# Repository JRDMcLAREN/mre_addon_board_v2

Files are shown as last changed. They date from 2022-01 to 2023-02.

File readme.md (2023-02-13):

# mre_addon_board_v2

Addon board for microrusEFI ECU.
Wideband controller wiring is based on https://github.com/mck1117/wideband, official rusEFI wideband controller.
This is a version using STM32F072C8Tx or STM32F072CBTx MCU in LQFP48 package.
(STM32F042C6T6 is not recommended for future release)

This addon board has build-in rusEFI wideband controller, microSD card slot and K-Thermocouple controller.
It can be used on all MREs with appropriate connector headers.

Wideband controller requires:
* CAN bus connectivity 
* additional power supply from 12V_MREL pin for sensor heater.
(not required for "my" MRE versions - R0.5.5rc, R0.6.1rc)

~~LSU 4.9 sensor wires are connected via MOLEX MicroFit 3x2 connector 43045-0601 or 43045-0612
K-Thermocouple wires are connected via MOLEX MicroFit 2x1 connector 43045-0202 or 43045-0212~~

Latest version use 2x4 pin connector MOLEX 43045-0800 or 43045-0812 (6pins for LSU and 2pins for K-Thermocouple).

Two analog outputs for external gauages are in progress.

SPI ChipSelect CS# pins:
PA15 - for EGT chip
PB9 - for microSD card

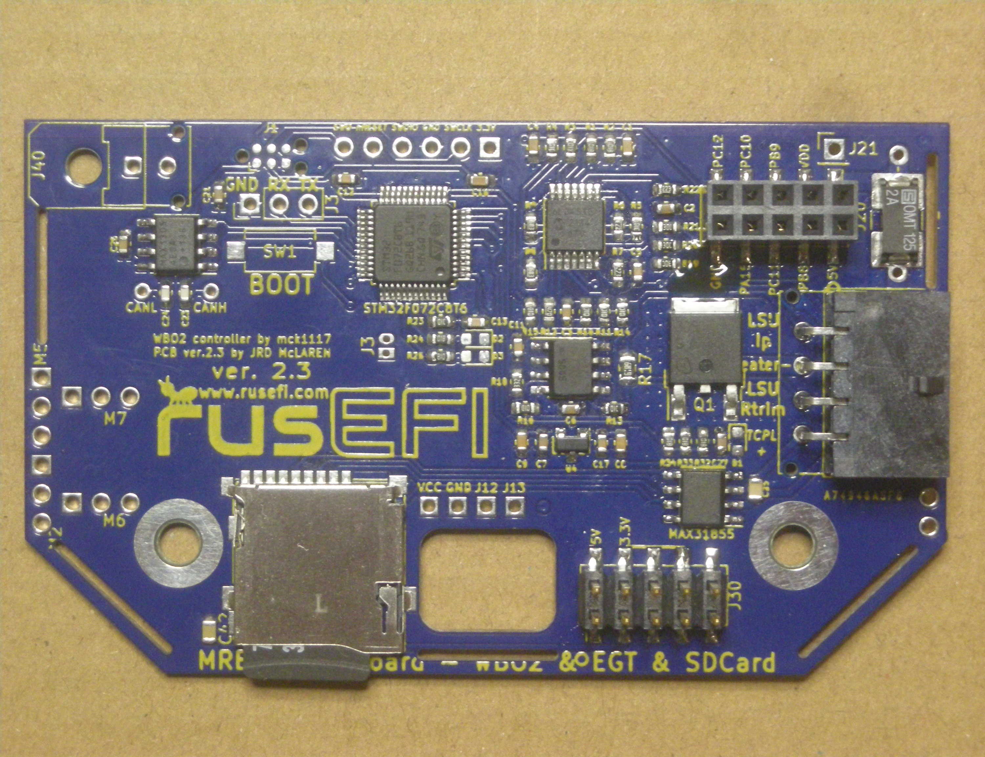
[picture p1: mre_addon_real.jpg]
mre_addon_board_v2


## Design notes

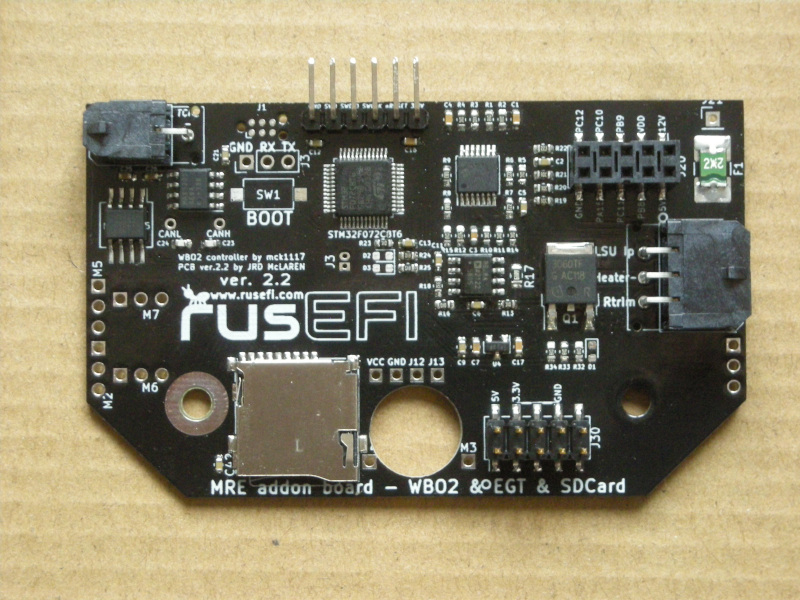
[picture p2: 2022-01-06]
mre_addon_real_v22.jpg

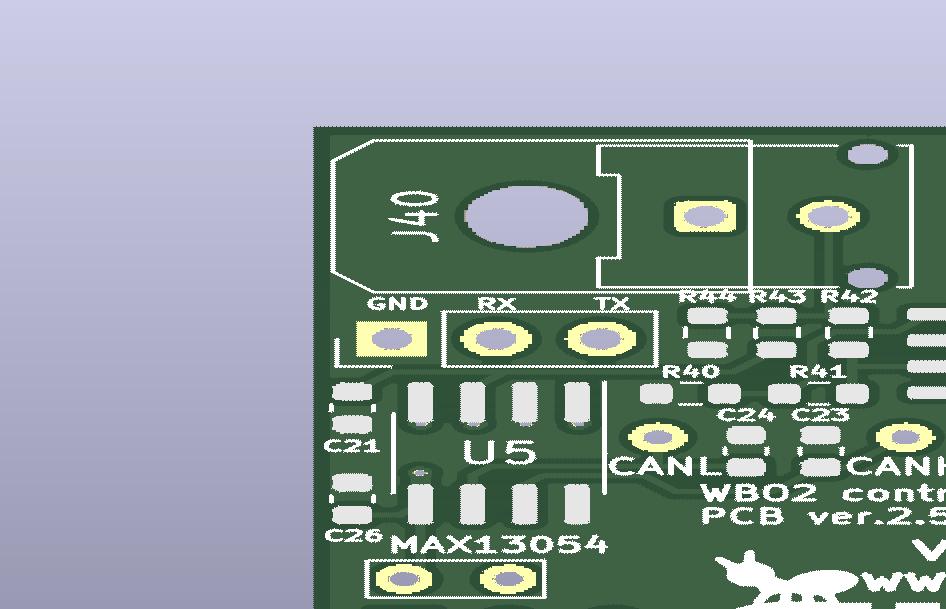
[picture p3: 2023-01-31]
mre_addon_v2.jpg

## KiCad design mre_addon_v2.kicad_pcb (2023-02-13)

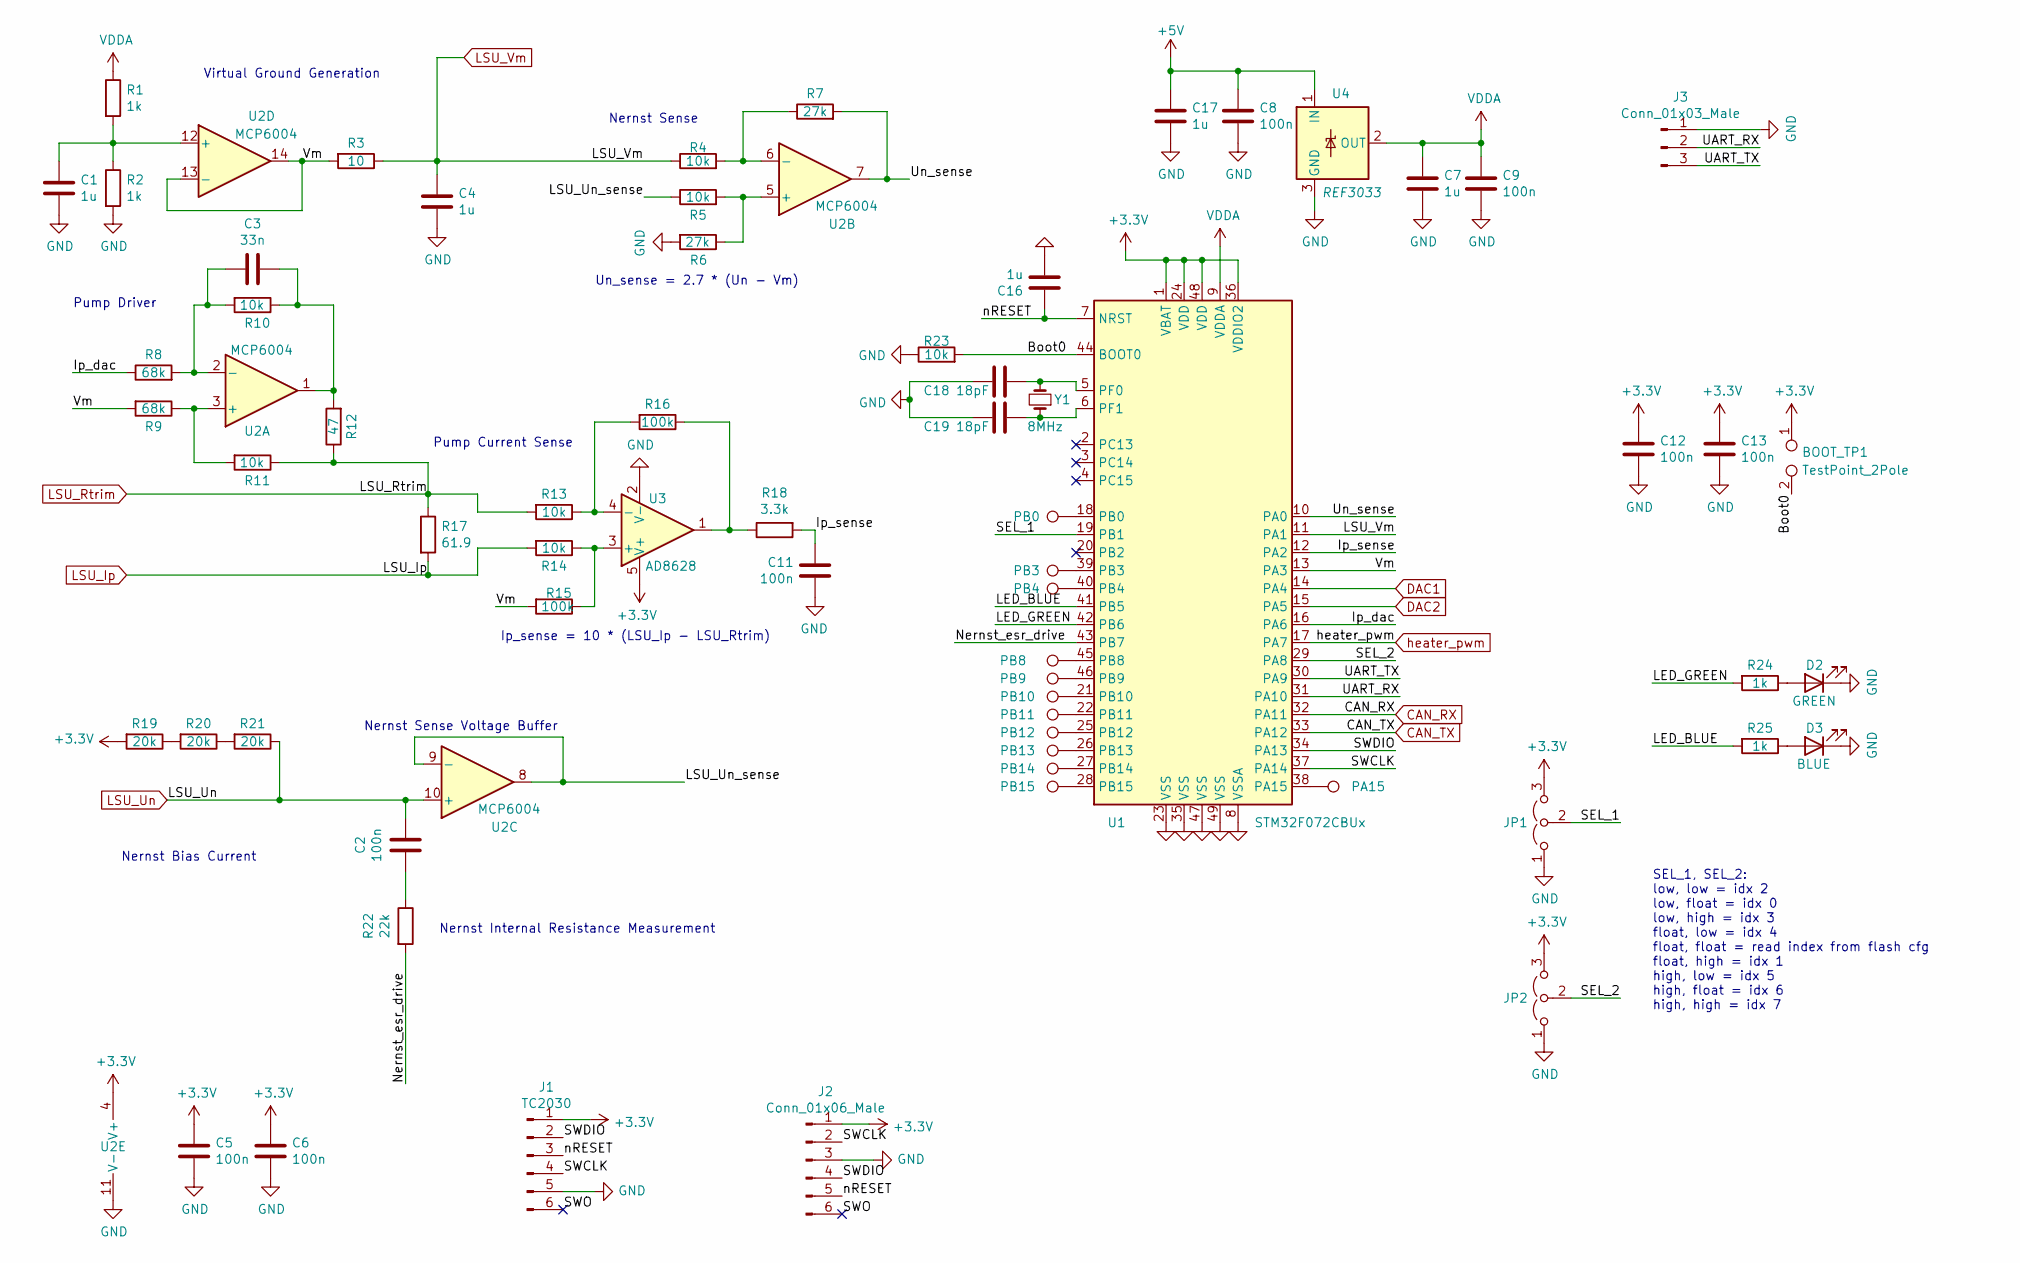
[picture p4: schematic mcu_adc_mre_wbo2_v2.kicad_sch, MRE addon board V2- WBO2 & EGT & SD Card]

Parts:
BOOT_TP1: TestPoint_2Pole; TestPoint_Bridge_Pitch2.54mm_Drill0.7mm
C1, C4, C7, C16, C17: 1u; C_0603_1608Metric; LCSC C52923
C2, C5, C6, C9, C11, C12, C13: 100n; C_0603_1608Metric; LCSC C1525
C3: 33n; C_0603_1608Metric; LCSC C1585
C8: 100n; C_0603_1608Metric
C18, C19: 18pF; C_0603_1608Metric
D2: GREEN; LED_0603_1608Metric; LCSC C72043
D3: BLUE; LED_0603_1608Metric; LCSC C72041
J1: TC2030; Tag-Connect_TC2030-IDC-NL_2x03_P1.27mm_Vertical
J2: Conn_01x06_Male; PinHeader_1x06_P2.54mm_Vertical
J3: Conn_01x03_Male; PinHeader_1x03_P2.54mm_Vertical
JP1, JP2: Jumper_3_Open; SolderJumper-3_P1.3mm_Open_Pad1.0x1.5mm
PA15: TestPoint; TestPoint_Pad_D1.0mm
PB0, PB3, PB4, PB8, PB9, PB10, PB11, PB12, PB13, PB14, PB15: TestPoint; TestPoint_Pad_D1.0mm
R1, R2, R24, R25: 1k; R_0603_1608Metric; LCSC C11702
R3: 10; R_0603_1608Metric; LCSC C25077
R4, R5, R10, R11, R13, R14, R23: 10k; R_0603_1608Metric; LCSC C25744
R6, R7: 27k; R_0603_1608Metric; LCSC C25771
R8, R9: 68k; R_0603_1608Metric; LCSC C36871
R12: 47; R_0603_1608Metric; LCSC C25118
R15, R16: 100k; R_0603_1608Metric; LCSC C25741
R17: 61.9; R_0603_1608Metric; LCSC C23092
R18: 3.3k; R_0603_1608Metric; LCSC C25890
R19, R20, R21: 20k; R_0603_1608Metric; LCSC C25765
R22: 22k; R_0603_1608Metric; LCSC C25768
U1: STM32F072CBUx; LQFP-48_7x7mm_P0.5mm
U2: MCP6004; TSSOP-14_4.4x5mm_P0.65mm; LCSC C50282
U3: AD8628; TSOT-23-5; LCSC C29309
U4: REF3033; SOT-23; LCSC C36658
Y1: 8MHz; Crystal_SMD_5032-2Pin_5.0x3.2mm

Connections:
+3.3V: BOOT_TP1.1, C5.1, C6.1, C12.1, C13.1, J1.1, J2.1, JP1.3 (B), JP2.3 (B), R19.2, U1.1 (VBAT), U1.24 (VDD), U1.36 (VDDIO2), U1.48 (VDD), U2.4 (V+), U3.5 (V+); also elsewhere on the board
+5V: C8.1, C17.1, U4.1 (IN); also elsewhere on the board
/mcu_adc_mre_wbo2_v2/Boot0: BOOT_TP1.2, R23.2, U1.44 (BOOT0)
/mcu_adc_mre_wbo2_v2/Ip_dac: R8.1, U1.16 (PA6)
/mcu_adc_mre_wbo2_v2/Ip_sense: C11.1, R18.2, U1.12 (PA2)
/mcu_adc_mre_wbo2_v2/LED_BLUE: R25.2, U1.41 (PB5)
/mcu_adc_mre_wbo2_v2/LED_GREEN: R24.2, U1.42 (PB6)
/mcu_adc_mre_wbo2_v2/LSU_Un_sense: R5.1, U2.8, U2.9 (-)
/mcu_adc_mre_wbo2_v2/Nernst_esr_drive: R22.2, U1.43 (PB7)
/mcu_adc_mre_wbo2_v2/SEL_1: JP1.2 (C), U1.19 (PB1)
/mcu_adc_mre_wbo2_v2/SEL_2: JP2.2 (C), U1.29 (PA8)
/mcu_adc_mre_wbo2_v2/SWCLK: J1.4, J2.2, U1.37 (PA14); also elsewhere on the board
/mcu_adc_mre_wbo2_v2/SWDIO: J1.2, J2.4, U1.34 (PA13); also elsewhere on the board
/mcu_adc_mre_wbo2_v2/SWO: J1.6, J2.6; also elsewhere on the board
/mcu_adc_mre_wbo2_v2/UART_RX: J3.2, U1.31 (PA10)
/mcu_adc_mre_wbo2_v2/UART_TX: J3.3, U1.30 (PA9)
/mcu_adc_mre_wbo2_v2/Un_sense: R7.2, U1.10 (PA0), U2.7
/mcu_adc_mre_wbo2_v2/Vm: R3.2, R9.2, R15.2, U1.13 (PA3), U2.13 (-), U2.14
/mcu_adc_mre_wbo2_v2/nRESET: C16.1, J1.3, J2.5, U1.7 (NRST); also elsewhere on the board
CAN_RX: U1.32 (PA11); also elsewhere on the board
CAN_TX: U1.33 (PA12); also elsewhere on the board
DAC1: U1.14 (PA4); also elsewhere on the board
DAC2: U1.15 (PA5); also elsewhere on the board
GND: C1.2, C4.2, C5.2, C6.2, C7.2, C8.2, C9.2, C11.2, C12.2, C13.2, C16.2, C17.2, C18.1, C19.1, D2.1 (K), D3.1 (K), J1.5, J2.3, J3.1, JP1.1 (A), JP2.1 (A), R2.2, R6.2, R23.1, U1.8 (VSSA), U1.23 (VSS), U1.35 (VSS), U1.47 (VSS), U1.49 (VSS), U2.11 (V-), U3.2 (V-), U4.3 (GND); also elsewhere on the board
LSU_Ip: R14.2, R17.2; also elsewhere on the board
LSU_Rtrim: R11.1, R12.1, R13.2, R17.1; also elsewhere on the board
LSU_Un: C2.1, R21.1, U2.10 (+); also elsewhere on the board
LSU_Vm: C4.1, R3.1, R4.1, U1.11 (PA1); also elsewhere on the board
unnamed: C1.1, R1.2, R2.1, U2.12 (+)
unnamed: C2.2, R22.1
unnamed: C3.1, R10.1, R12.2, U2.1
unnamed: C3.2, R8.2, R10.2, U2.2 (-)
unnamed: C18.2, U1.5 (PF0), Y1.2
unnamed: C19.2, U1.6 (PF1), Y1.1
unnamed 54: D2.2 (A), R24.1; also elsewhere on the board
unnamed 55: D3.2 (A), R25.1; also elsewhere on the board
unnamed: PA15.1, U1.38 (PA15)
unnamed: PB0.1, U1.18 (PB0)
unnamed: PB3.1, U1.39 (PB3)
unnamed: PB4.1, U1.40 (PB4)
unnamed: PB8.1, U1.45 (PB8)
unnamed: PB9.1, U1.46 (PB9)
unnamed: PB10.1, U1.21 (PB10)
unnamed: PB11.1, U1.22 (PB11)
unnamed: PB12.1, U1.25 (PB12)
unnamed: PB13.1, U1.26 (PB13)
unnamed: PB14.1, U1.27 (PB14)
unnamed: PB15.1, U1.28 (PB15)
unnamed: R4.2, R7.1, U2.6 (-)
unnamed: R5.2, R6.1, U2.5 (+)
unnamed: R9.1, R11.2, U2.3 (+)
unnamed 72: R13.1, R16.2, U3.4 (-); also elsewhere on the board
unnamed 73: R14.1, R15.1, U3.3 (+); also elsewhere on the board
unnamed 74: R16.1, R18.1, U3.1; also elsewhere on the board
unnamed: R19.1, R20.2
unnamed: R20.1, R21.2
VDDA: C7.1, C9.1, R1.1, U1.9 (VDDA), U4.2 (OUT)
heater_pwm: U1.17 (PA7); also elsewhere on the board

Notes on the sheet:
Un_sense = 2.7 * (Un - Vm)
Virtual Ground Generation
Pump Current Sense
Pump Driver
Ip_sense = 10 * (LSU_Ip - LSU_Rtrim)
Nernst Sense
Nernst Internal Resistance Measurement
Nernst Sense Voltage Buffer
SEL_1, SEL_2: low, low = idx 2 low, float = idx 0 low, high = idx 3 float, low = idx 4 float, float = read index from flash cfg float, high = idx 1 high, low = idx 5 high, float = idx 6 high, high = idx 7
Nernst Bias Current

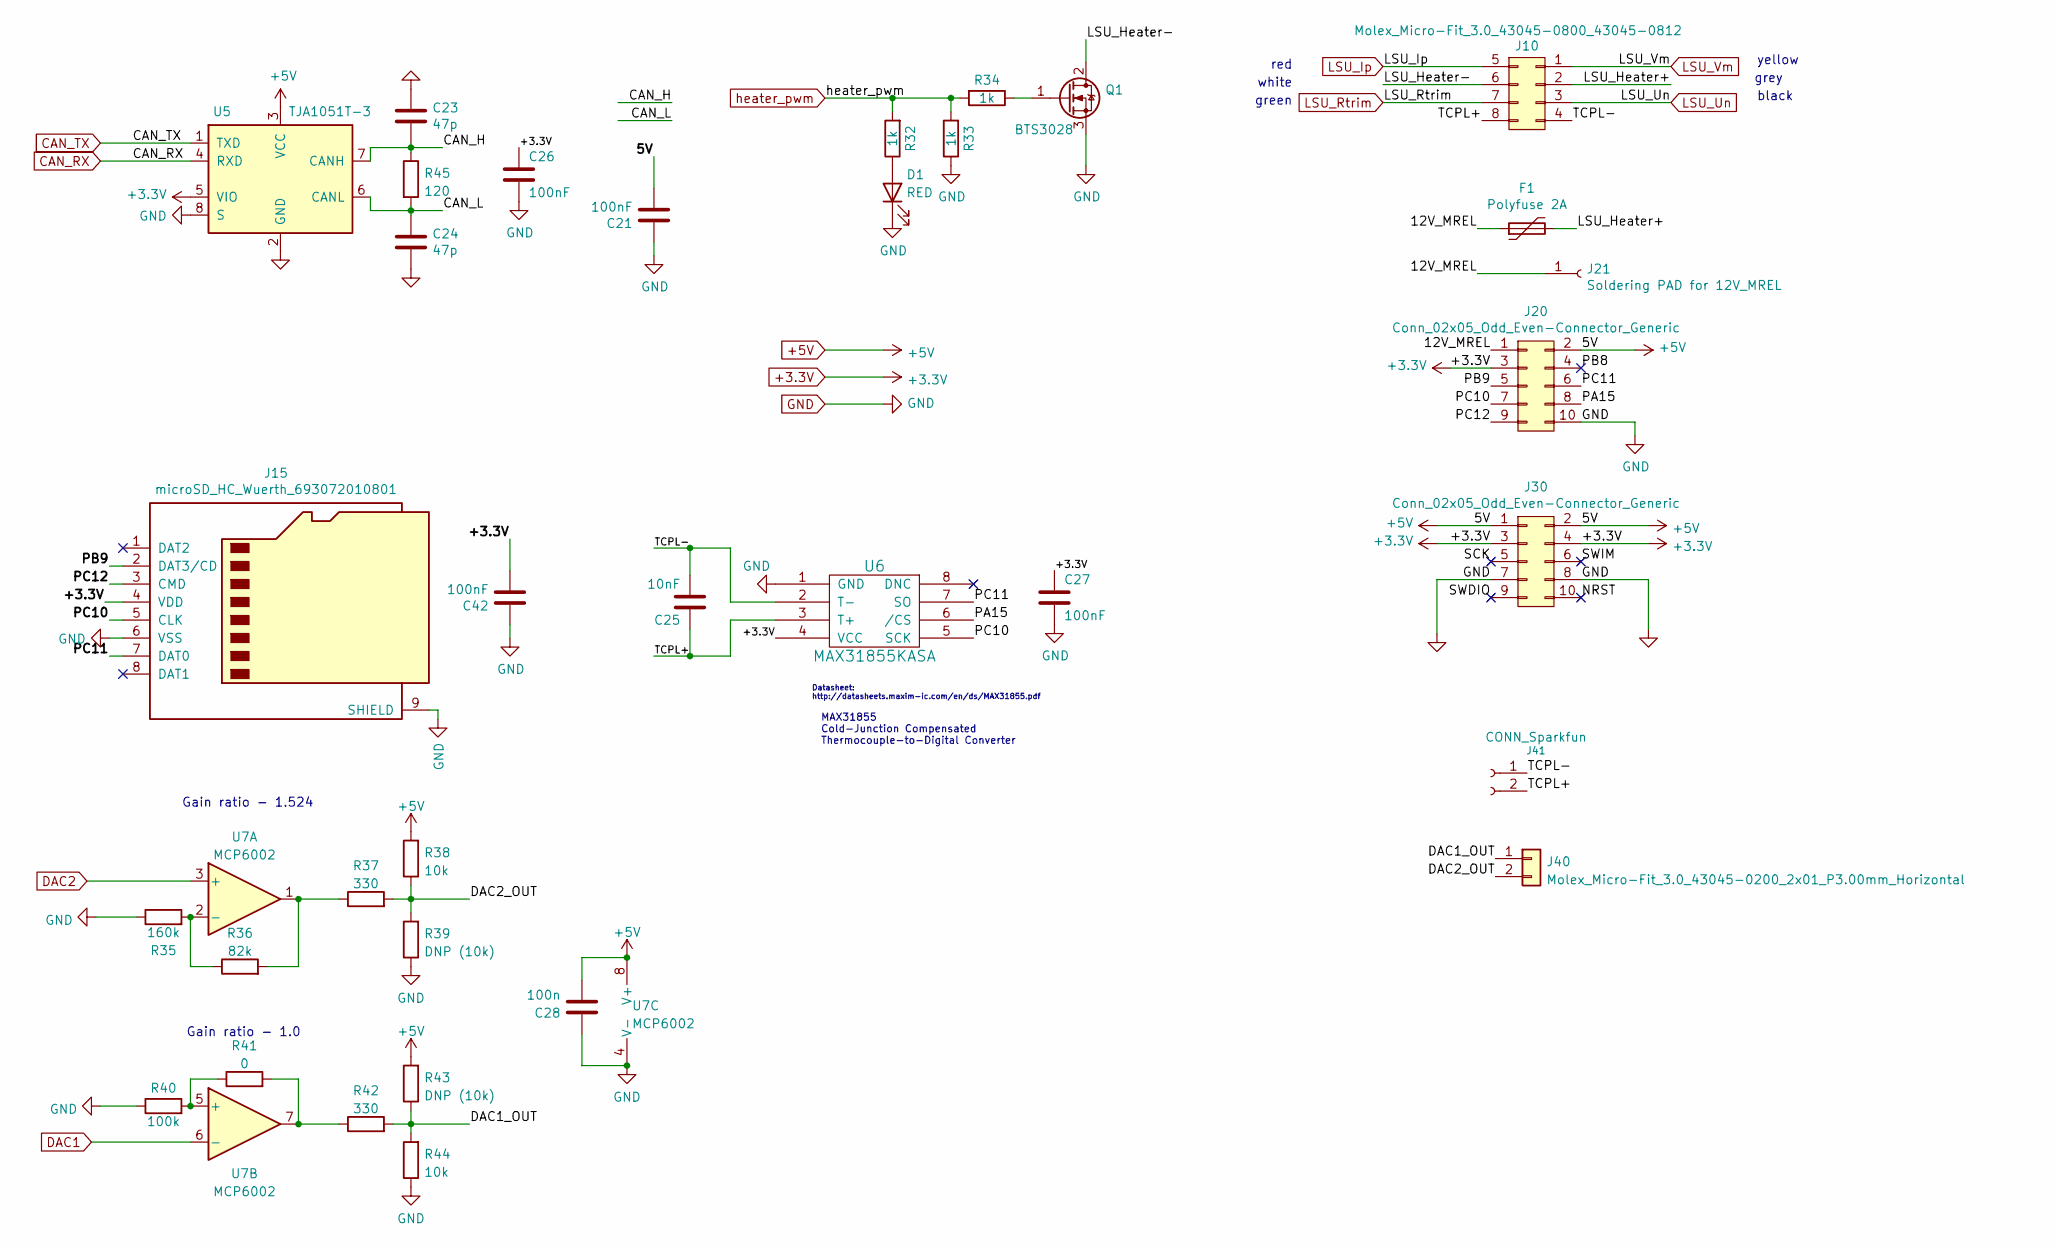
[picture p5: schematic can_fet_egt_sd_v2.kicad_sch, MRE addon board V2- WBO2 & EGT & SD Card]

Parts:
C21, C42: 100nF; C_0603_1608Metric; Part # C0603C104J5RACTU; LCSC C14663
C23, C24: 47p; C_0603_1608Metric; LCSC C1567
C25: 10nF; C_0603_1608Metric
C26, C27: 100nF; C_0603_1608Metric
C28: 100n; C_0603_1608Metric
D1: RED; LED_0603_1608Metric; LCSC C2286
F1: Polyfuse 2A; R_2816_7142Metric
J10: Molex_Micro-Fit_3.0_43045-0800_43045-0812; Molex_Micro-Fit_3.0_43045-0800_2x04_P3.00mm_Horizontal
J15: microSD_HC_Wuerth_693072010801; LCSC N/A
J20, J30: Conn_02x05_Odd_Even-Connector_Generic; PinHeader_2x05_P2.54mm_Vertical_SMD
J21: Soldering PAD for 12V_MREL; PinHeader_1x01_P2.54mm_Vertical
J40: Molex_Micro-Fit_3.0_43045-0200_2x01_P3.00mm_Horiz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; Molex_Micro-Fit_3.0_43045-0200_2x01_P3.00mm_Horizontal
J41: CONN_Sparkfun; tcpl_PCC-SMP
Q1: BTS3028; TO-252-2; LCSC C112639
R32, R33, R34: 1k; R_0603_1608Metric; LCSC C11702
R35: 160k; R_0603_1608Metric
R36: 82k; R_0603_1608Metric
R37, R42: 330; R_0603_1608Metric
R38, R44: 10k; R_0603_1608Metric
R39, R43: DNP (10k); R_0603_1608Metric
R40: 100k; R_0603_1608Metric
R41: 0; R_0603_1608Metric
R45: 120; R_0805_2012Metric
U5: TJA1051T-3; SOIC-8_3.9x4.9mm_P1.27mm; LCSC C38695
U6: MAX31855KASA; SOIC-8_3.9x4.9mm_P1.27mm
U7: MCP6002; SOIC-8_3.9x4.9mm_P1.27mm

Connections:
+3.3V: C26.1, C27.1, C42.2, J15.4 (VDD), J20.3, J30.3, J30.4, U5.5 (VIO), U6.4 (VCC); also elsewhere on the board
+5V: C21.2, C28.2, J20.2, J30.1, J30.2, R38.2, R43.2, U5.3 (VCC), U7.8 (V+); also elsewhere on the board
/can_fet_egt_sd_v2/12V_MREL: F1.1, J20.1, J21.1; also elsewhere on the board
/can_fet_egt_sd_v2/CAN_H: C23.2, R45.1, U5.7 (CANH); also elsewhere on the board
/can_fet_egt_sd_v2/CAN_L: C24.1, R45.2, U5.6 (CANL); also elsewhere on the board
/can_fet_egt_sd_v2/DAC1_OUT: J40.1, R42.2, R43.1, R44.2; also elsewhere on the board
/can_fet_egt_sd_v2/DAC2_OUT: J40.2, R37.2, R38.1, R39.2; also elsewhere on the board
/can_fet_egt_sd_v2/LSU_Heater+: F1.2, J10.2; also elsewhere on the board
/can_fet_egt_sd_v2/LSU_Heater-: J10.6, Q1.2 (D); also elsewhere on the board
/can_fet_egt_sd_v2/NRST: J30.10; also elsewhere on the board
/can_fet_egt_sd_v2/PA15: J20.8, U6.6 (/CS); also elsewhere on the board
/can_fet_egt_sd_v2/PB8: J20.4; also elsewhere on the board
/can_fet_egt_sd_v2/PB9: J15.2 (DAT3/CD), J20.5; also elsewhere on the board
/can_fet_egt_sd_v2/PC10: J15.5 (CLK), J20.7, U6.5 (SCK); also elsewhere on the board
/can_fet_egt_sd_v2/PC11: J15.7 (DAT0), J20.6, U6.7 (SO); also elsewhere on the board
/can_fet_egt_sd_v2/PC12: J15.3 (CMD), J20.9; also elsewhere on the board
/can_fet_egt_sd_v2/SCK: J30.5; also elsewhere on the board
/can_fet_egt_sd_v2/SWDIO: J30.9; also elsewhere on the board
/can_fet_egt_sd_v2/SWIM: J30.6; also elsewhere on the board
/can_fet_egt_sd_v2/TCPL+: C25.1, J10.8, J41.2, U6.3 (T+); also elsewhere on the board
/can_fet_egt_sd_v2/TCPL-: C25.2, J10.4, J41.1, U6.2 (T-); also elsewhere on the board
CAN_RX: U5.4 (RXD); also elsewhere on the board
CAN_TX: U5.1 (TXD); also elsewhere on the board
DAC1: U7.6 (-); also elsewhere on the board
DAC2: U7.3 (+); also elsewhere on the board
GND: C21.1, C23.1, C24.2, C26.2, C27.2, C28.1, C42.1, D1.1 (K), J15.6 (VSS), J15.9 (SHIELD), J20.10, J30.7, J30.8, Q1.3 (S), R33.1, R35.1, R39.1, R40.1, R44.1, U5.2 (GND), U5.8 (S), U6.1 (GND), U7.4 (V-); also elsewhere on the board
LSU_Ip: J10.5; also elsewhere on the board
LSU_Rtrim: J10.7; also elsewhere on the board
LSU_Un: J10.3; also elsewhere on the board
LSU_Vm: J10.1; also elsewhere on the board
unnamed 53: D1.2 (A), R32.1; also elsewhere on the board
unnamed: Q1.1 (G), R34.1
unnamed: R35.2, R36.1, U7.2 (-)
unnamed: R36.2, R37.1, U7.1
unnamed: R40.2, R41.1, U7.5 (+)
unnamed: R41.2, R42.1, U7.7
heater_pwm: R32.2, R33.2, R34.2; also elsewhere on the board

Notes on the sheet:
MAX31855 Cold-Junction Compensated Thermocouple-to-Digital Converter
white
Gain ratio - 1.524
Gain ratio - 1.0
green
grey
red
black
Datasheet: http://datasheets.maxim-ic.com/en/ds/MAX31855.pdf
yellow

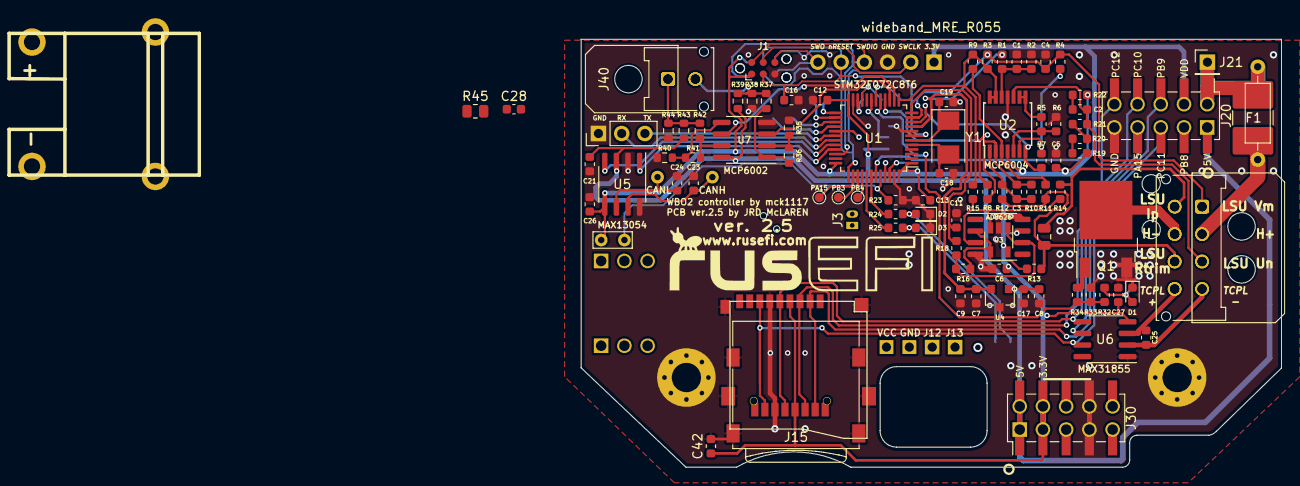
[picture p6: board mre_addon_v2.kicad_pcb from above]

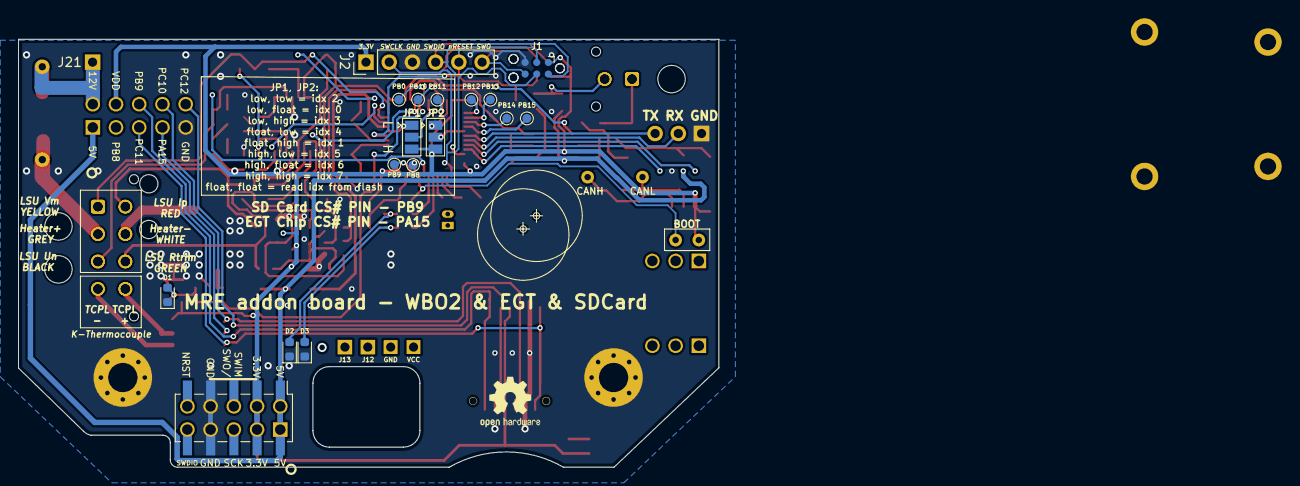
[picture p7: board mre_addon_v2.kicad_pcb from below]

Board: 2 copper layers, 76.6 x 46.8 mm, 116 parts (19 on the bottom side), 83 nets.

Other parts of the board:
D1#2: RED; LED_0603_1608Metric
D2#2: GREEN; LED_0603_1608Metric
D3#2: BLUE; LED_0603_1608Metric
F1#2: Polyfuse 2A; R_Axial_DIN0207_L6.3mm_D2.5mm_P10.16mm_Horizontal
G1: LOGO; mre_logo
H1, H2: MountingHole_3.2mm_M3_Pad_Via
J1#2: TC2030; Tag-Connect_TC2030-IDC-NL_2x03_P1.27mm_Vertical
J10#2: Molex_Micro-Fit_3.0_43045-0800_43045-0812; Molex_Micro-Fit_3.0_43045-0812_2x04_P3.00mm_Vertical
J15x: MICRO-SDCARD-CONNECTOR-3300060P1
J30x: Conn_02x05_Odd_Even-Connector_Generic; PinHeader_2x05_P2.54mm_Vertical_SMD
J40#2: Molex_Micro-Fit_3.0_43045-0200_2x01_P3.00mm_Horiz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; Molex_Micro-Fit_3.0_43045-0200_2x01_P3.00mm_Horizontal
LOGO1: DNP; OSHW-Logo2_7.3x6mm_SilkScreen
U0: wideband_MRE_R055
U3x: SO-8_3.9x4.9mm_P1.27mm

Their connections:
+3.3V: J1#2.1, J15x.4, J30x.3, J30x.4, U0.J203, U0.J204, U0.J804, U3x.7; also elsewhere on the board
+5V: J30x.1, J30x.2, U0.J201, U0.J202, U0.J801; also elsewhere on the board
/can_fet_egt_sd_v2/12V_MREL: F1#2.1, U0.J802; also elsewhere on the board
/can_fet_egt_sd_v2/CAN_H: U0.J49; also elsewhere on the board
/can_fet_egt_sd_v2/CAN_L: U0.J50; also elsewhere on the board
/can_fet_egt_sd_v2/DAC1_OUT: J40#2.1; also elsewhere on the board
/can_fet_egt_sd_v2/DAC2_OUT: J40#2.2; also elsewhere on the board
/can_fet_egt_sd_v2/LSU_Heater+: F1#2.2, J10#2.2; also elsewhere on the board
/can_fet_egt_sd_v2/LSU_Heater-: J10#2.6; also elsewhere on the board
/can_fet_egt_sd_v2/NRST: J30x.9, U0.J210; also elsewhere on the board
/can_fet_egt_sd_v2/PA15: U0.J807; also elsewhere on the board
/can_fet_egt_sd_v2/PB8: U0.J803; also elsewhere on the board
/can_fet_egt_sd_v2/PB9: J15x.2, U0.J806; also elsewhere on the board
/can_fet_egt_sd_v2/PC10: J15x.5, U0.J808; also elsewhere on the board
/can_fet_egt_sd_v2/PC11: J15x.7, U0.J805; also elsewhere on the board
/can_fet_egt_sd_v2/PC12: J15x.3, U0.J810; also elsewhere on the board
/can_fet_egt_sd_v2/SCK: J30x.6, U0.J205; also elsewhere on the board
/can_fet_egt_sd_v2/SWDIO: J30x.10, U0.J209; also elsewhere on the board
/can_fet_egt_sd_v2/SWIM: J30x.5, U0.J206; also elsewhere on the board
/can_fet_egt_sd_v2/TCPL+: J10#2.8; also elsewhere on the board
/can_fet_egt_sd_v2/TCPL-: J10#2.4; also elsewhere on the board
/mcu_adc_mre_wbo2_v2/SWCLK: J1#2.4; also elsewhere on the board
/mcu_adc_mre_wbo2_v2/SWDIO: J1#2.2; also elsewhere on the board
/mcu_adc_mre_wbo2_v2/SWO: J1#2.6; also elsewhere on the board
/mcu_adc_mre_wbo2_v2/nRESET: J1#2.3; also elsewhere on the board
GND: D1#2.1 (K), D2#2.1 (K), D3#2.1 (K), H1.1, H2.1, J1#2.5, J15x.6, J15x.G1, J15x.G2, J15x.G3, J15x.G4, J30x.7, J30x.8, U0.J207, U0.J208, U0.J809, U3x.4, U3x.8; also elsewhere on the board
LSU_Ip: J10#2.5; also elsewhere on the board
LSU_Rtrim: J10#2.7; also elsewhere on the board
LSU_Un: J10#2.3; also elsewhere on the board
LSU_Vm: J10#2.1; also elsewhere on the board
unnamed 53: D1#2.2 (A); also elsewhere on the board
unnamed 54: D2#2.2 (A); also elsewhere on the board
unnamed 55: D3#2.2 (A); also elsewhere on the board
unnamed 72: U3x.2; also elsewhere on the board
unnamed 73: U3x.3; also elsewhere on the board
unnamed 74: U3x.6; also elsewhere on the board

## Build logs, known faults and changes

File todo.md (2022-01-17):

- ~~fix footprint for MA31855KASA~~
- ~~fix footprint J15x for sdcard & move it up~~
- ~~fix program header pin order~~
- ~~replace C23 C24~~
- ~~replace LEDS D2 D3 on bottom side~~
- ~~replace EGT header on same side as WBO2 header~~
- ~~add silkscreen instruction for ChipSelect CS#~~
- add silkscreen frame for BT module on bottom side
- ~~make marks for holes (for CAP on mre board)~~

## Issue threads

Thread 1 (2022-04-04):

JRDMcLAREN, your website is down! We can't access files.

dsladventure, 2022-04-04:
Hello, dear JRDMcLAREN.

ASUS DSL-N10_C1 USB mod
We cannot access your server for the DSL-N10 mod via the relevant IP address.

http://195.28.90.62/dohc/dsl-n10-c1/

Can you help us about accesing that mod files?

JRDMcLAREN, 2022-04-05:
This in not MRE addon board relevant issue ... !

Closed 2022-04-05.

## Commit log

2023-01-19 ver2.5 in progress
    [can_fet_egt_sd.sch, can_fet_egt_sd_v2.sch, mcu_adc_mre_wbo2_v2.sch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]
2023-01-26 V2.5 with OPAmp
    [can_fet_egt_sd_v2.kicad_sch, mcu_adc_mre_wbo2_v2.kicad_sch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]
2023-01-26 BOM ver2.3
2023-02-04 tried to improve wording
    I'm not sure to have understood original description for " MRE versions pre R0.5.5rc" correctly!
    Please edit or comment in case I had wrong understanding
2023-02-05 some changes on DAC pins
    [can_fet_egt_sd_v2.kicad_sch, mcu_adc_mre_wbo2_v2.kicad_sch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]
2023-02-13 V2.5 - 13.02.2023
    [mre_addon_v2-B_Pasta.gbr, mre_addon_v2-F_Pasta.gbr]
